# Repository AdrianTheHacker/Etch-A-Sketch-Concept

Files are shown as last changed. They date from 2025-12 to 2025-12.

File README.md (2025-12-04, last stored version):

# Etchasketch Concept
This project is designed to be a concept of what an etchasketch could be. It'll allow for modern features that aid artist ability, and truly allow them to *Draw the Future*.

## Requirements
In no particular order, the requirements are as follows:
1. Display has at least 3 colours (white counts as a colour).
2. Display can update at least once per second.
3. Users can control the drawing cursor of the display using rotary inputs which read input a minimum of every 10ms*.
4. The product should be at most 77mm by 100mm by 40mm.
5. Users can save the current drawing on the display on a laptop.
6. Different devices can share a given drawing session to collaborate on designs.

*Note that the rate in which an input is processed is independent of the rate in which the screen will be updating.

## Specifications
* [1] E-Ink display capable of displaying 3 different colours.
* [1] Single button for cycling between colours.
* [2] E-Ink screen uses effective partial updating algorithm for reducing.
* [3] Two potentiometers for reading user inputs.
* [4] PCB has width of 100mm and length of 77mm.
* [5/6] PCB contains a [pre-certified WiFi module](https://www.adafruit.com/product/4201).
* [5/6] Desktop app for managing drawing sessions and saving drawing state.

## Component Selection
Sorted by sub-system.

### Processing
[STM32G4 Hardware Configuration](https://www.st.com/resource/en/application_note/an5093-getting-started-with-stm32g4-series--hardware-development-boards-stmicroelectronics.pdf)
- [2x] [Ceramic capacitor 100nF](https://www.mouser.ca/ProductDetail/TAIYO-YUDEN/MAJCH168BB7104KTEA01?qs=ZcfC38r4PovaTBrG0IdezQ%3D%3D)
- [1x] [Ceramic capacitor 4.7uF](https://www.mouser.ca/ProductDetail/TAIYO-YUDEN/LMK107BJ475KA-T?qs=PzICbMaShUfCoRlxZeLF0g%3D%3D)
- [3x] [Ceramic capacitor 1uF (No CAD Found)](https://www.mouser.ca/ProductDetail/Murata-Electronics/GCM188M8EH105KE08D?qs=ZcfC38r4Posf7JVKT9w1zw%3D%3D)
- [1x] [Ceramic capacitor 10nF](https://www.mouser.ca/ProductDetail/KYOCERA-AVX/06035A103JAT2A?qs=Cw3yY7soYCOJ7MBOLgA8ng%3D%3D)
- [2x] [Ceramic capacitor 6.8pF (No CAD Found)](https://www.mouser.ca/ProductDetail/KYOCERA-AVX/0603YA6R8CAT2A?qs=Q0wCMCRSJ1u%252BWh5kh2d1zQ%3D%3D)
- [2x] [Ceramic capacitor 20pF](https://www.mouser.ca/ProductDetail/KYOCERA-AVX/06031A200KAT2A?qs=vKkcnSRGkVsINiHJTia7rw%3D%3D)
- [1x] [Ferrite beads (No CAD Found)](https://www.mouser.ca/ProductDetail/TE-Connectivity-Sigma-Inductors/BMC-Q1E0000H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)
- [1x] [Quartz 24MHz (No CAD Found)](https://www.mouser.ca/ProductDetail/KYOCERA-AVX/CX3225FB24000C0FZZH1?qs=Tc%252BHE9vUsnugTp3oEWKKRg%3D%3D)
- [1x] [Quartz 32.764kHz](https://www.mouser.ca/ProductDetail/Vishay-Dale/XT1312HHRXX32K76E?qs=jcD%2FCkGBYeMqyUz9UpSqCw%3D%3D)
- [1x] [Resistor 390Ω](https://www.mouser.ca/ProductDetail/Vishay-Beyschlag/MCT0603MD3900BP500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)
- [3x] [Resistor 10kΩ](https://www.mouser.ca/ProductDetail/TE-Connectivity-Holsworthy/RA73F1J10KBTDF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)
- [1x] [ST-Link Debugger (STLINK-V3MINIE)](https://www.mouser.ca/ProductDetail/STMicroelectronics/STLINK-V3MINIE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)
- [1x] [ST-Link debugger connector (LibraryLoader didn't work)](https://www.digikey.ca/en/products/detail/samtec-inc/FTSH-107-01-F-DV-K/2650001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)
- [1x] [STM32G484QET6](https://www.mouser.ca/ProductDetail/STMicroelectronics/STM32G484QET6?qs=uwxL4vQweFOef65amZQ%252BrA%3D%3D)
- [1x] [Switch (No CAD Found)](https://mou.sr/4ixqZ2V)
- [1x] [Pushbutton](https://www.mouser.ca/ProductDetail/CK/PTS125SM73SMTR21M-LFS?qs=t7xnP681wgVp4NpaUUvA%252Bw%3D%3D)

### Power
- [1x] [CR2032 Battery](https://www.mouser.ca/ProductDetail/Murata-Electronics/CR2032?qs=gTYE2QTfZfQ%2FQrgScp89FQ%3D%3D)
- [1x] [CR2032 Connector](https://www.mouser.ca/ProductDetail/Renata/SMTU2032-C?qs=UxeAxwACbqkmlMDdDbz%2FoA%3D%3D)
- [1x] [Power on LED Green](https://www.mouser.ca/ProductDetail/ams-OSRAM/KT-EELP41.12-S2U1-25-2X4X-5-R18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)
- [1x] [Resistor 100Ω (for LED) (No CAD Found, Not Requested)](https://www.mouser.ca/ProductDetail/TE-Connectivity-Holsworthy/RT73F1J100RBTD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)
- [1x] [Ceramic capacitor 10uF](https://www.mouser.ca/ProductDetail/KYOCERA-AVX/0603YD106MAT2A?qs=%252BdQmOuGyFcGTGabFXpuZrg%3D%3D)

### Display
[Screen's circuit diagram (Make manually)](https://cdn-shop.adafruit.com/product-files/6393/P6393+C22273-001_datasheet_ZJY296152-0266EABMFGN-R.pdf)
- [1x] [E-Ink display tri-colour 2.66In diagonal](https://www.adafruit.com/product/6393)
- [9x] [Ceramic capacitor 1uF](https://www.mouser.ca/ProductDetail/TAIYO-YUDEN/MAJCT168BB7105KTEA01?qs=ZcfC38r4PotKRnvquyYkSA%3D%3D)
- [1x] [Resistor 2.2Ω (No CAD Found, Not Requested)](https://www.mouser.ca/ProductDetail/Wurth-Elektronik/560112116088?qs=mELouGlnn3eIPFCFgc7e7A%3D%3D)
- [3x] [Diode](https://www.mouser.ca/ProductDetail/onsemi/MBR0530T1G?qs=3JMERSakeboS%2FFOxJUMWeg%3D%3D)
- [1x] [NMOS](https://www.mouser.ca/ProductDetail/Nexperia/NX3008NBKS115?qs=N31o%252Bt096gvSMWdFEcaa8A%3D%3D)
- [1x] [Inductor 47uH (No CAD Found, Not Requested)](https://www.mouser.ca/ProductDetail/Sumida/CDRH2D18-LDNP-470NC?qs=mT6umqgwvA1P4peHEoEcxg%3D%3D)
- [1x] [Screen connector (Downloaded, Add Manually)](https://www.digikey.ca/en/products/detail/w%C3%BCrth-elektronik/687124149022/5047796)

### Controls
- [1x] [Accelerometer](https://www.mouser.ca/ProductDetail/Analog-Devices/ADXL345BCCZ?qs=WIvQP4zGanhoa7YOkGtvEg%3D%3D)
- [1x] [Ceramic capacitor 100nF](https://www.mouser.ca/ProductDetail/TAIYO-YUDEN/MAJCH168BB7104KTEA01?qs=ZcfC38r4PovaTBrG0IdezQ%3D%3D)
- [1x] [Tantalum capacitor 1uF](https://www.mouser.ca/ProductDetail/KYOCERA-AVX/TACL105K010FTA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)
- [2x] [Potentiometer 10KΩ (Create Manually)](https://www.adafruit.com/product/3395)
- [2x] [Potentiometer cap](https://www.adafruit.com/product/2057)
- [2x] [Pushbutton](https://www.mouser.ca/ProductDetail/CK/PTS125SM73SMTR21M-LFS?qs=t7xnP681wgVp4NpaUUvA%252Bw%3D%3D)
- [2x] [Resistor 10kΩ](https://www.mouser.ca/ProductDetail/TE-Connectivity-Holsworthy/RA73F1J10KBTDF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)

### Connectivity
- [1x] [WiFi Module (Make Manually, Base off of pin headers)](https://www.adafruit.com/product/4201)
- [3x] [Pin header (Sets of 4)](https://www.mouser.ca/ProductDetail/HARTING/14120416050000?qs=sGAEpiMZZMvlX3nhDDO4ADo1TeYw%2F5hz1M8q0I2khik%3D)

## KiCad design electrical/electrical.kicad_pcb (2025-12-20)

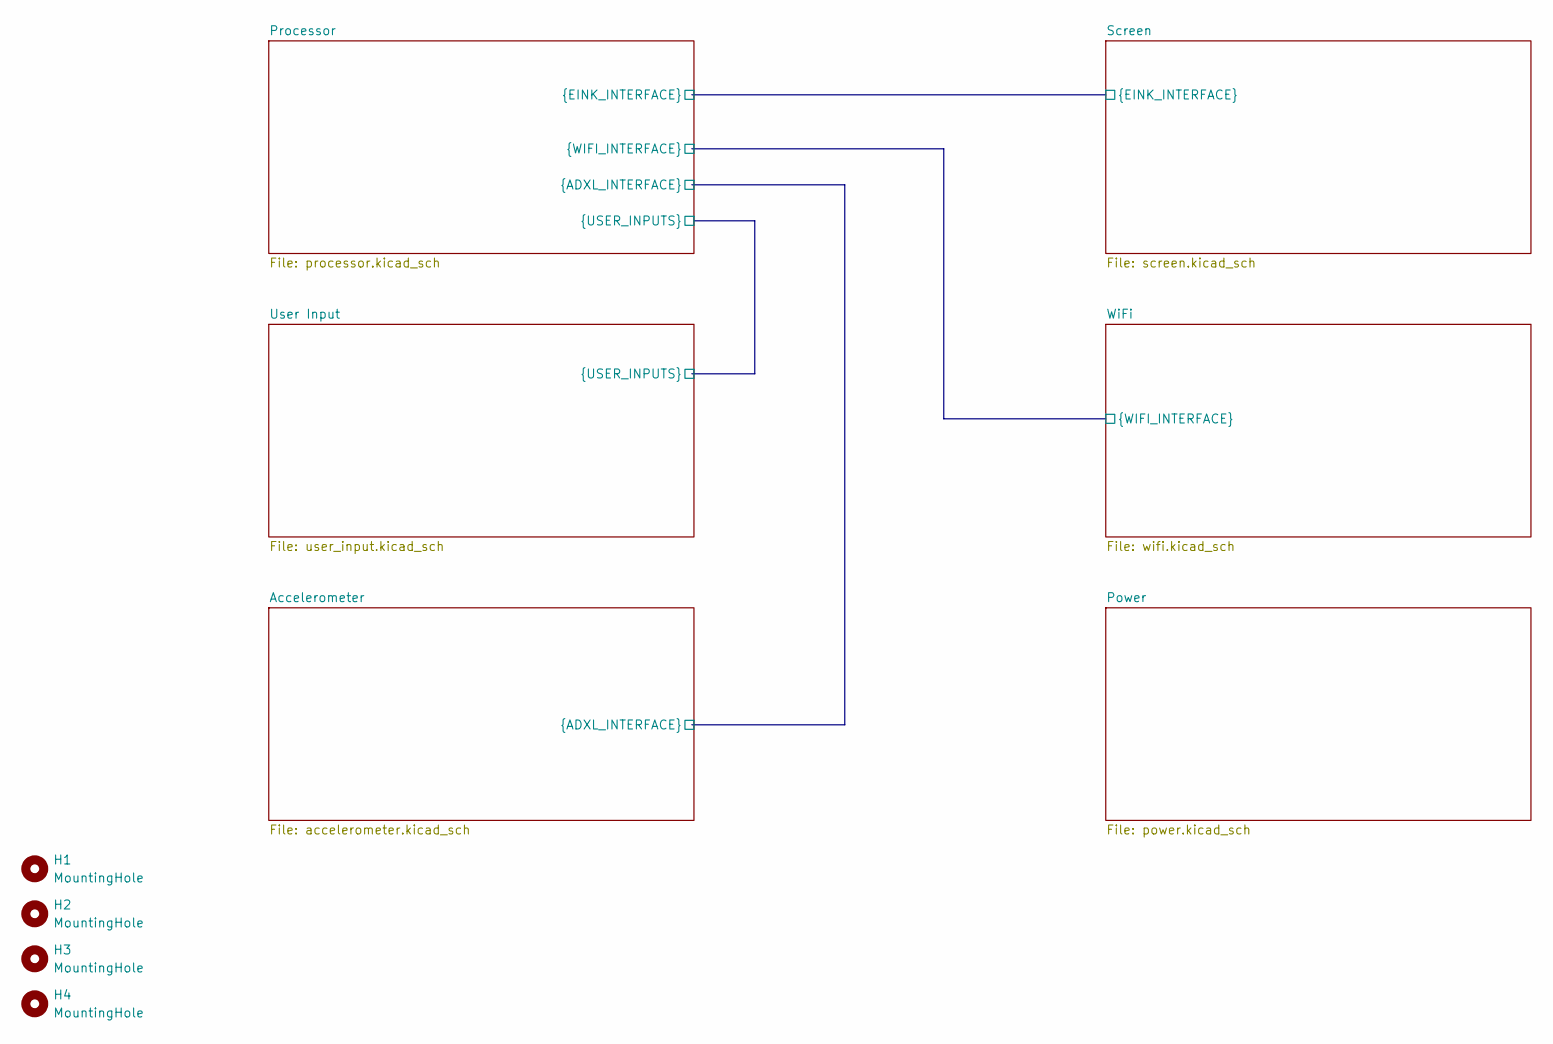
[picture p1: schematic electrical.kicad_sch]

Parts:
H1, H2, H3, H4: MountingHole; MountingHole_2.2mm_M2

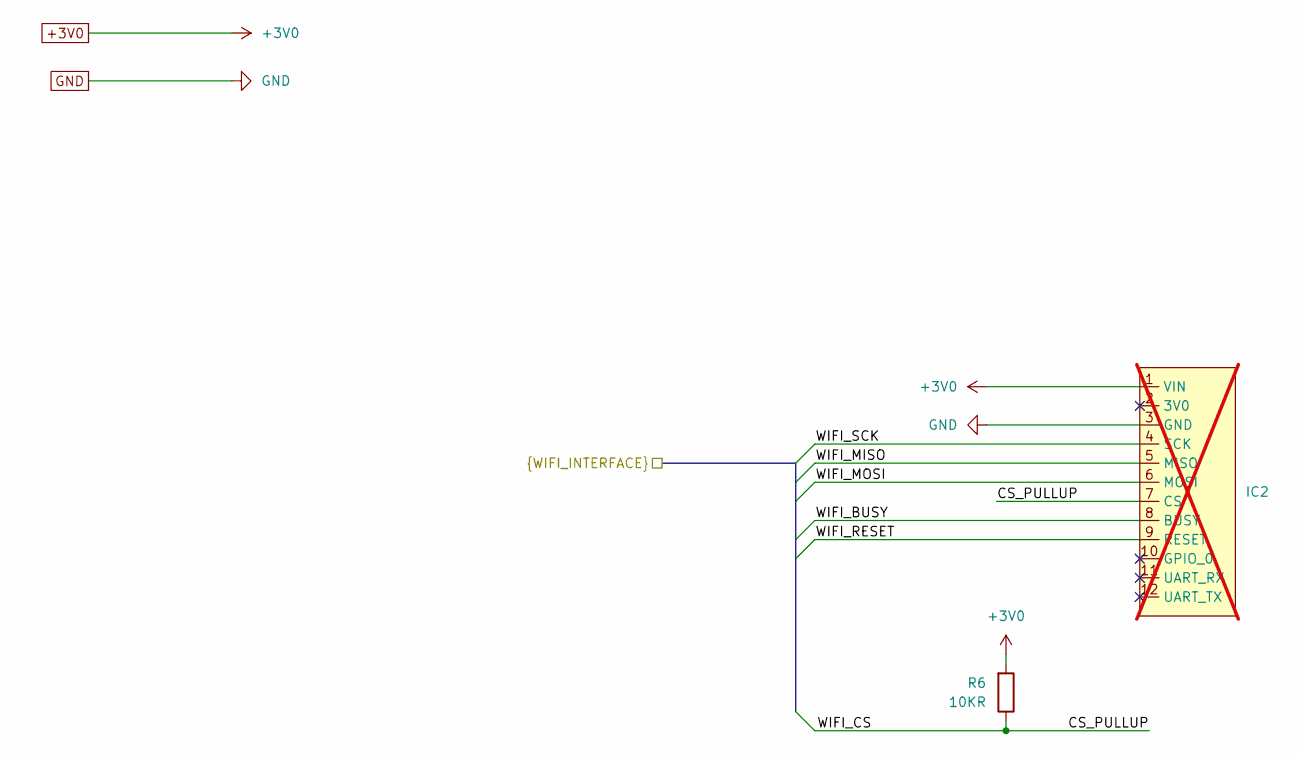
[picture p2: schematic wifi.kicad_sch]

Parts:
IC2: THT_WIFI_MODULE; not fitted
R6: 10KR; SMD_RESISTOR_0603

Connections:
+3V0: IC2.1 (VIN), R6.2; also elsewhere on the board
/Processor/WIFI_BUSY: IC2.8 (BUSY); also elsewhere on the board
/Processor/WIFI_CS: IC2.7 (CS), R6.1; also elsewhere on the board
/Processor/WIFI_MISO: IC2.5 (MISO); also elsewhere on the board
/Processor/WIFI_MOSI: IC2.6 (MOSI); also elsewhere on the board
/Processor/WIFI_RESET: IC2.9 (RESET); also elsewhere on the board
/Processor/WIFI_SCK: IC2.4 (SCK); also elsewhere on the board
GND: IC2.3 (GND); also elsewhere on the board

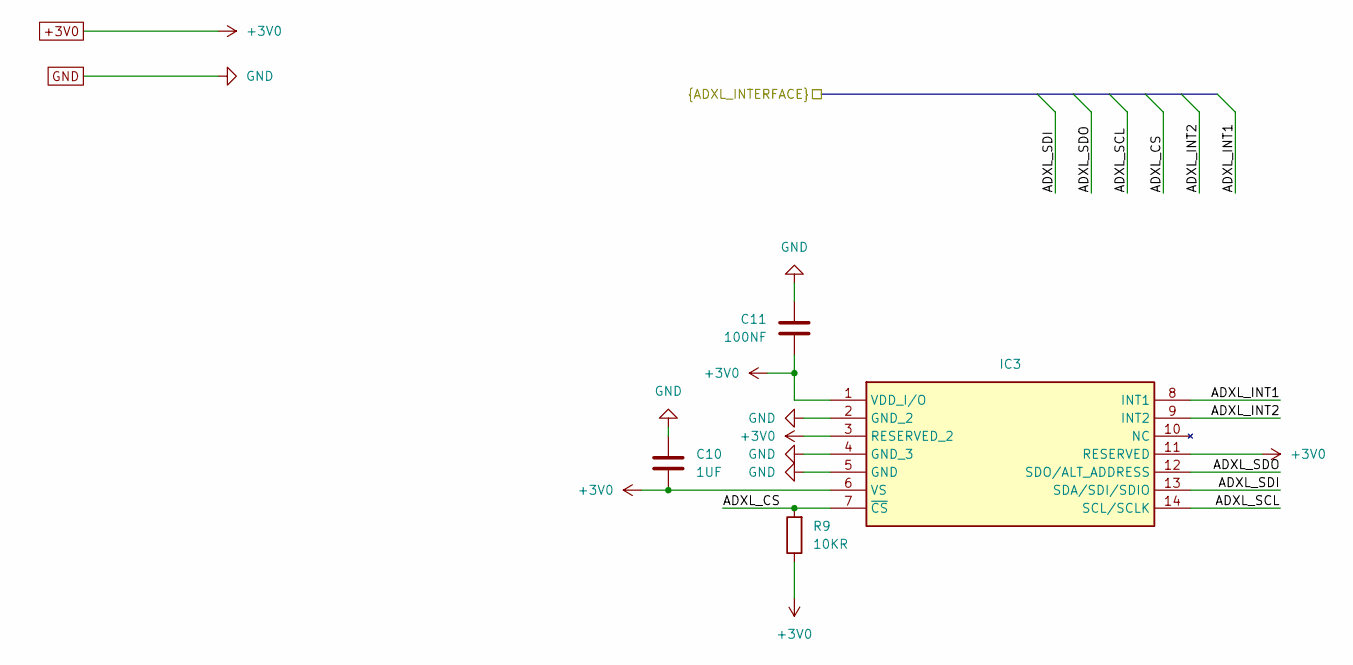
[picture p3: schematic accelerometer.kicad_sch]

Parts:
C10: 1UF; SMD_CAPACITOR_TANTALUM_0603_1UF
C11: 100NF; SMD_CAPACITOR_CERAMIC_0603
IC3: SMD_ADXL345BCCZ
R9: 10KR; SMD_RESISTOR_0603

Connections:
+3V0: C10.2, C11.1, IC3.1 (VDD_I/O), IC3.3 (RESERVED_2), IC3.6 (VS), IC3.11 (RESERVED), R9.1; also elsewhere on the board
/Accelerometer/ADXL_CS: IC3.7 (~CS), R9.2; also elsewhere on the board
/Accelerometer/ADXL_INT1: IC3.8 (INT1); also elsewhere on the board
/Accelerometer/ADXL_INT2: IC3.9 (INT2); also elsewhere on the board
/Accelerometer/ADXL_SCL: IC3.14 (SCL/SCLK); also elsewhere on the board
/Accelerometer/ADXL_SDI: IC3.13 (SDA/SDI/SDIO); also elsewhere on the board
/Accelerometer/ADXL_SDO: IC3.12 (SDO/ALT_ADDRESS); also elsewhere on the board
GND: C10.1, C11.2, IC3.2 (GND_2), IC3.4 (GND_3), IC3.5 (GND); also elsewhere on the board

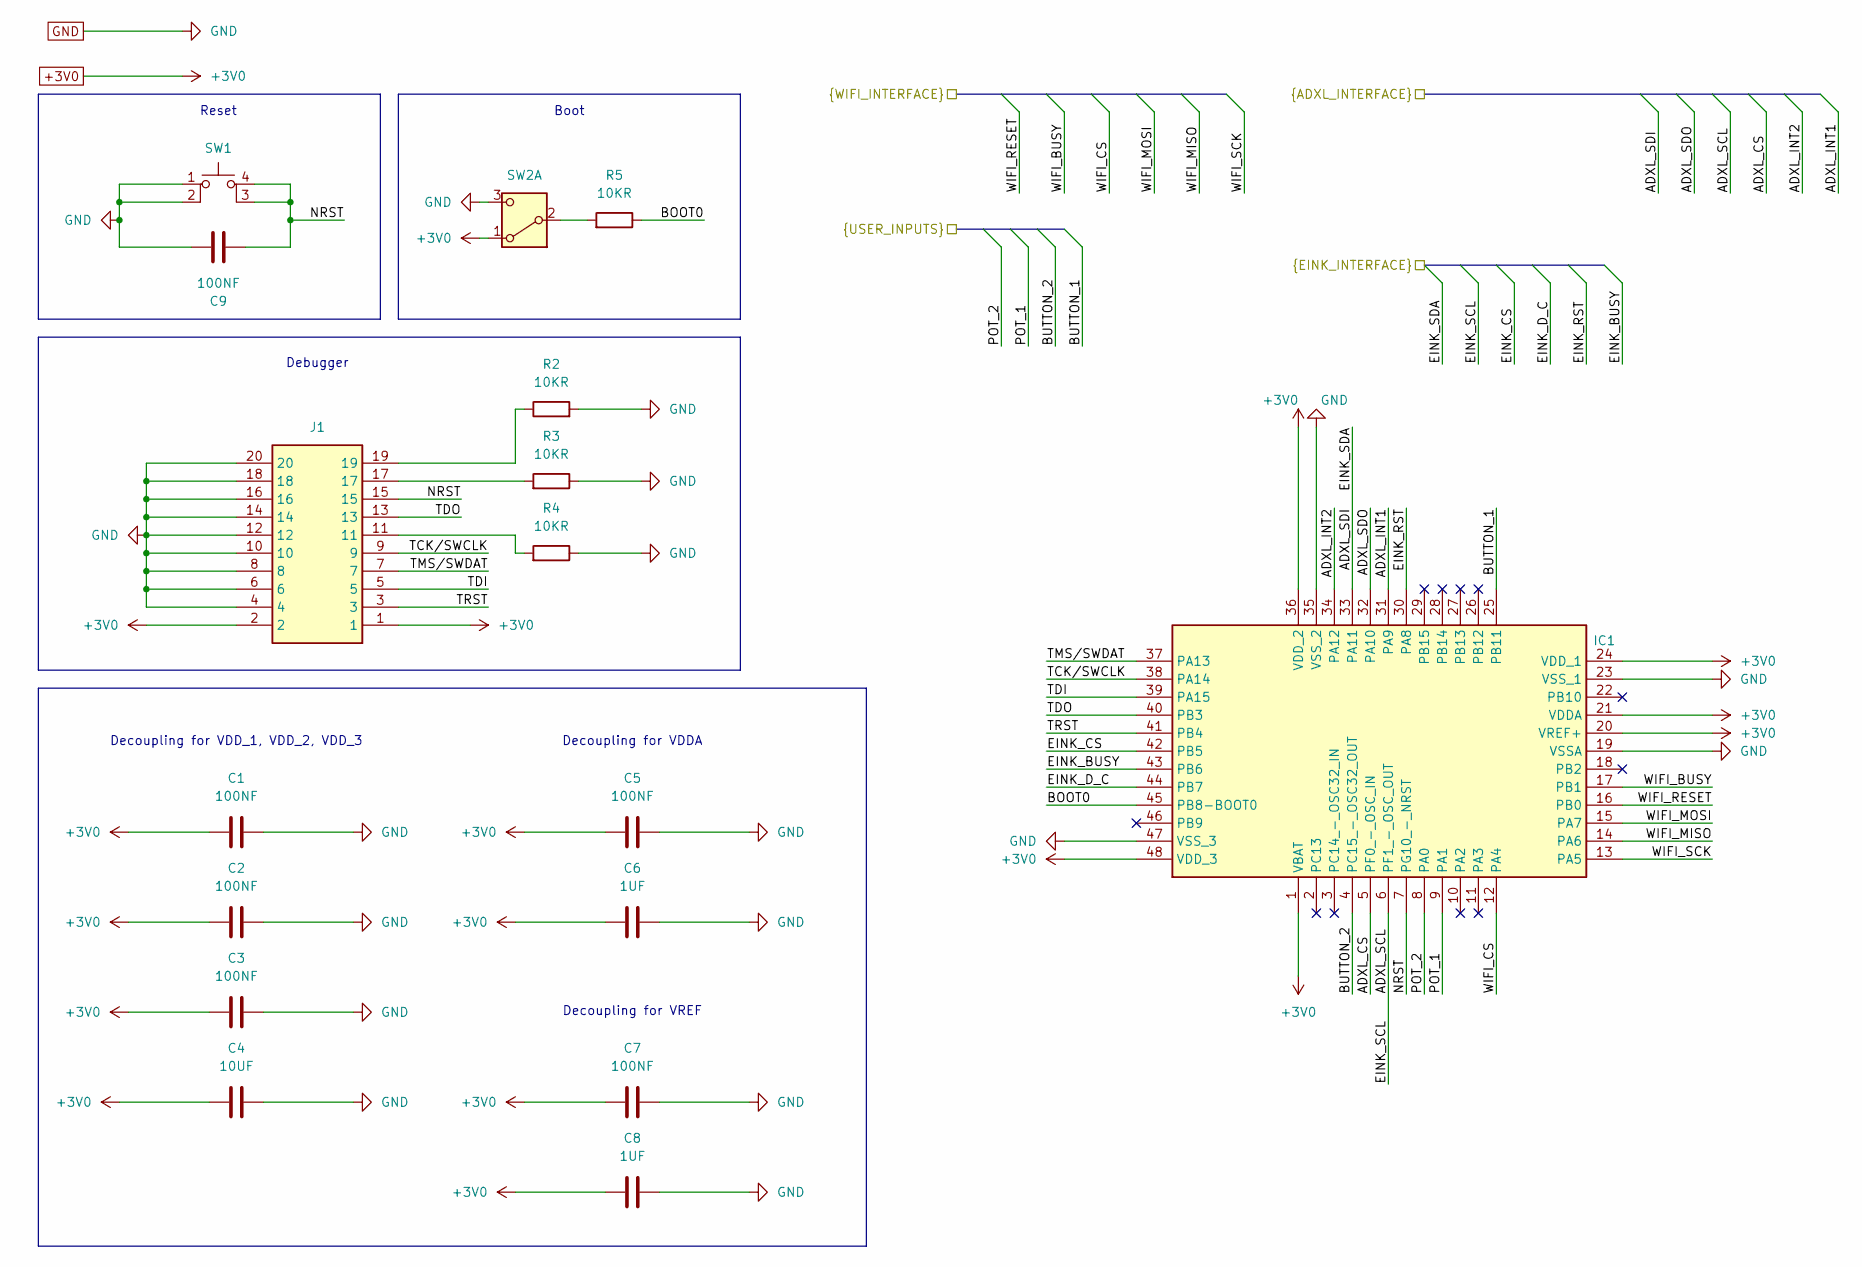
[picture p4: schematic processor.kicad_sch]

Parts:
C1, C2, C3, C5, C7, C9: 100NF; SMD_CAPACITOR_CERAMIC_0603
C4: 10UF; SMD_CAPACITOR_CERAMIC_0603
C6, C8: 1UF; SMD_CAPACITOR_CERAMIC_0603
IC1: STM32G474CBT6TR; SMD_STM32G474CBT6TR
J1: 24 Pins; THT_CONNECTOR_JTAG_SWD
R2, R3, R4, R5: 10KR; SMD_RESISTOR_0603
SW1: SMD_BUTTON
SW2: SMD_SWITCH_HORIZONTAL

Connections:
+3V0: C1.2, C2.2, C3.2, C4.1, C5.2, C6.1, C7.2, C8.1, IC1.1 (VBAT), IC1.20 (VREF+), IC1.21 (VDDA), IC1.24 (VDD_1), IC1.36 (VDD_2), IC1.48 (VDD_3), J1.1, J1.2, SW2.1 (A); also elsewhere on the board
/Accelerometer/ADXL_CS: IC1.5 (PF0_-_OSC_IN); also elsewhere on the board
/Accelerometer/ADXL_INT1: IC1.31 (PA9); also elsewhere on the board
/Accelerometer/ADXL_INT2: IC1.34 (PA12); also elsewhere on the board
/Accelerometer/ADXL_SCL: IC1.6 (PF1_-_OSC_OUT); also elsewhere on the board
/Accelerometer/ADXL_SDI: IC1.33 (PA11); also elsewhere on the board
/Accelerometer/ADXL_SDO: IC1.32 (PA10); also elsewhere on the board
/Processor/BOOT0: IC1.45 (PB8-BOOT0), R5.1
/Processor/BUTTON_1: IC1.25 (PB11); also elsewhere on the board
/Processor/BUTTON_2: IC1.4 (PC15_-_OSC32_OUT); also elsewhere on the board
/Processor/EINK_BUSY: IC1.43 (PB6); also elsewhere on the board
/Processor/EINK_CS: IC1.42 (PB5); also elsewhere on the board
/Processor/EINK_D_C: IC1.44 (PB7); also elsewhere on the board
/Processor/EINK_RST: IC1.30 (PA8); also elsewhere on the board
/Processor/NRST: C9.1, IC1.7 (PG10_-_NRST), J1.15, SW1.3 (K), SW1.4 (A)
/Processor/POT_1: IC1.9 (PA1); also elsewhere on the board
/Processor/POT_2: IC1.8 (PA0); also elsewhere on the board
/Processor/TCK/SWCLK: IC1.38 (PA14), J1.9
/Processor/TDI: IC1.39 (PA15), J1.5
/Processor/TDO: IC1.40 (PB3), J1.13
/Processor/TMS/SWDAT: IC1.37 (PA13), J1.7
/Processor/TRST: IC1.41 (PB4), J1.3
/Processor/WIFI_BUSY: IC1.17 (PB1); also elsewhere on the board
/Processor/WIFI_CS: IC1.12 (PA4); also elsewhere on the board
/Processor/WIFI_MISO: IC1.14 (PA6); also elsewhere on the board
/Processor/WIFI_MOSI: IC1.15 (PA7); also elsewhere on the board
/Processor/WIFI_RESET: IC1.16 (PB0); also elsewhere on the board
/Processor/WIFI_SCK: IC1.13 (PA5); also elsewhere on the board
GND: C1.1, C2.1, C3.1, C4.2, C5.1, C6.2, C7.1, C8.2, C9.2, IC1.19 (VSSA), IC1.23 (VSS_1), IC1.35 (VSS_2), IC1.47 (VSS_3), J1.4, J1.6, J1.8, J1.10, J1.12, J1.14, J1.16, J1.18, J1.20, R2.2, R3.1, R4.1, SW1.1, SW1.2, SW2.3 (C); also elsewhere on the board
unnamed: J1.11, R4.2
unnamed: J1.17, R3.2
unnamed: J1.19, R2.1
unnamed: R5.2, SW2.2 (B)

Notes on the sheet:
Debugger
Reset
Boot
Decoupling for VDDA
Decoupling for VDD_1, VDD_2, VDD_3
Decoupling for VREF

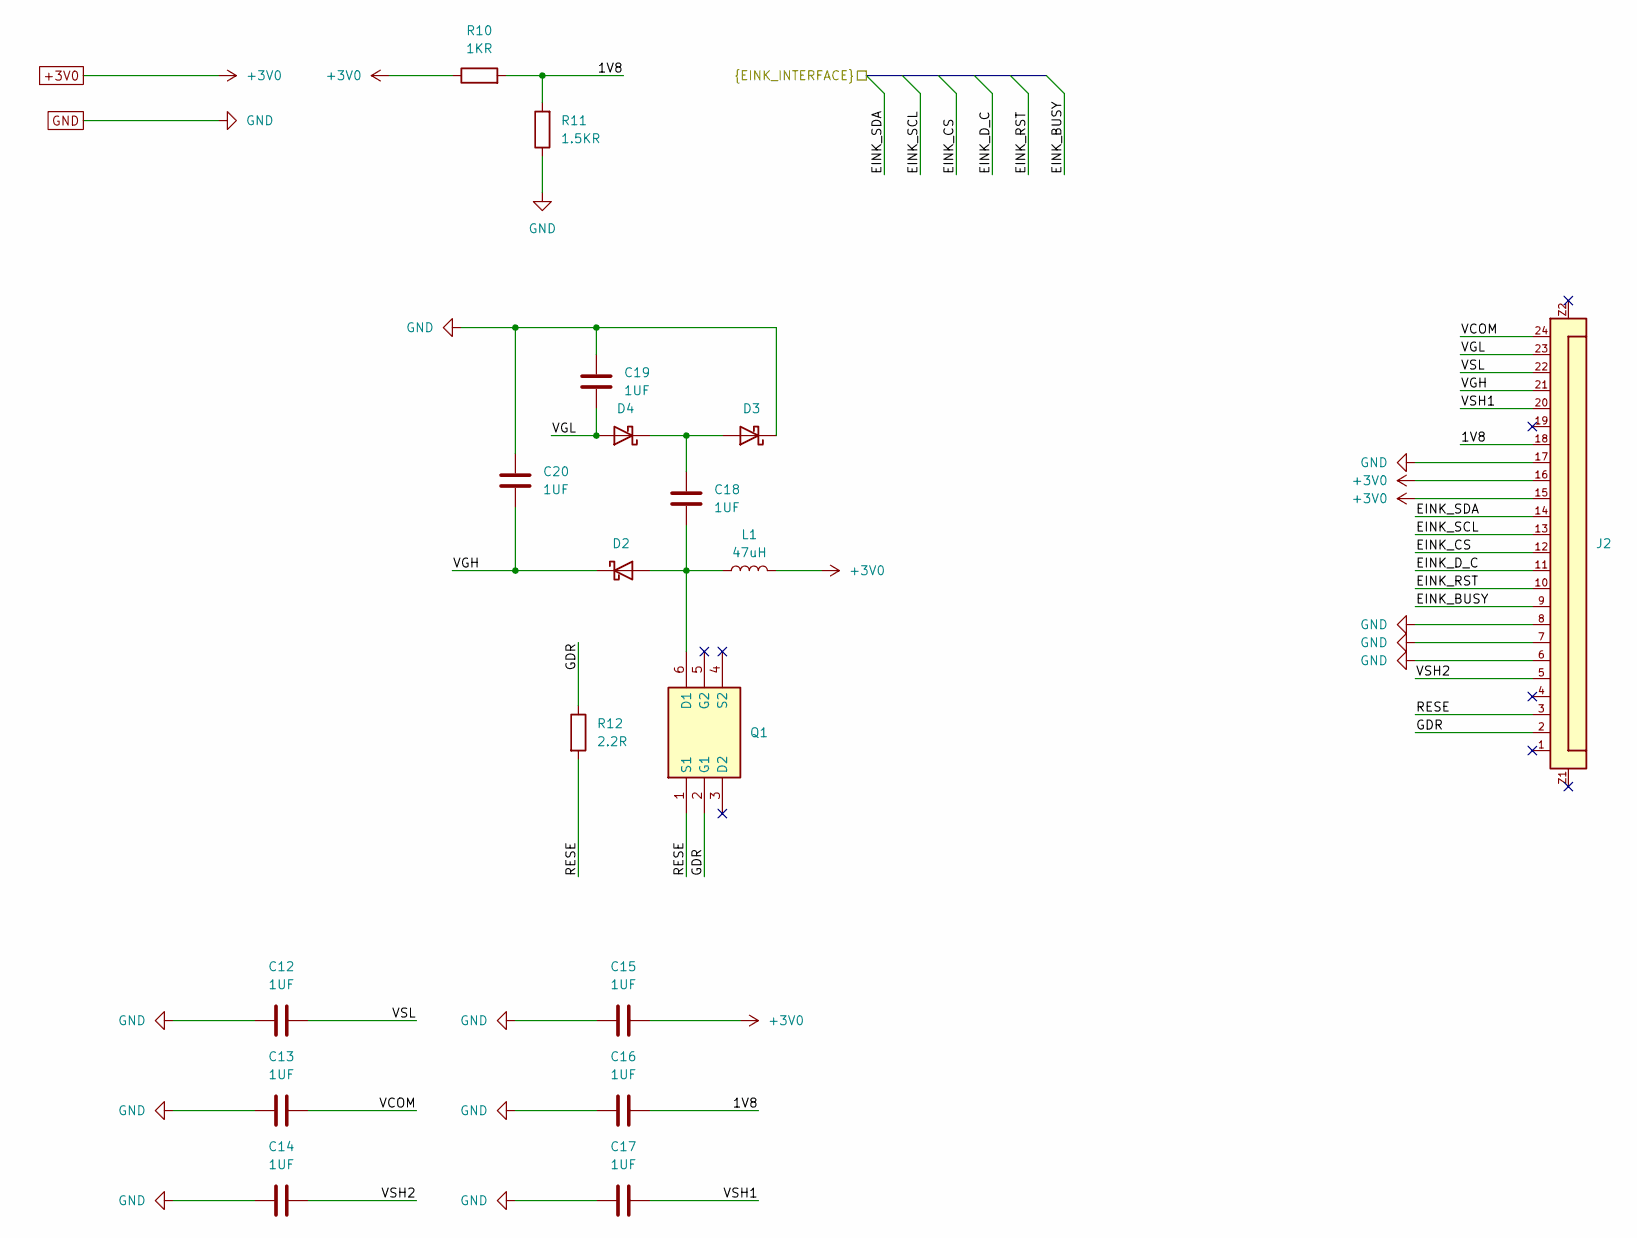
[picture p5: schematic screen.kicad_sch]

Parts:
C12, C13, C14, C15, C16, C17, C18, C19, C20: 1UF; SMD_CAPACITOR_CERAMIC_0603
D2, D3, D4: SMD_DIODE_MBR0530T1G
J2: 6871XX149022_687124149022; SMD_CONNECTOR_RIBBON_CABLE_24_PINS
L1: 47uH; SMD_INDUCTOR_0603
Q1: SMD_MOSFET_NX3008NBKS
R10: 1KR; SMD_RESISTOR_0603
R11: 1.5KR; SMD_RESISTOR_0603
R12: 2.2R; SMD_RESISTOR_0603

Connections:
+3V0: C15.2, J2.15, J2.16, L1.2, R10.1; also elsewhere on the board
/Accelerometer/ADXL_SCL: J2.13; also elsewhere on the board
/Accelerometer/ADXL_SDI: J2.14; also elsewhere on the board
/Processor/EINK_BUSY: J2.9; also elsewhere on the board
/Processor/EINK_CS: J2.12; also elsewhere on the board
/Processor/EINK_D_C: J2.11; also elsewhere on the board
/Processor/EINK_RST: J2.10; also elsewhere on the board
/Screen/1V8: C16.2, J2.18, R10.2, R11.2
/Screen/GDR: J2.2, Q1.2 (G1), R12.2
/Screen/RESE: J2.3, Q1.1 (S1), R12.1
/Screen/VCOM: C13.1, J2.24
/Screen/VGH: C20.2, D2.1 (K), J2.21
/Screen/VGL: C19.1, D4.2 (A), J2.23
/Screen/VSH1: C17.2, J2.20
/Screen/VSH2: C14.2, J2.5
/Screen/VSL: C12.1, J2.22
GND: C12.2, C13.2, C14.1, C15.1, C16.1, C17.1, C19.2, C20.1, D3.1 (K), J2.6, J2.7, J2.8, J2.17, R11.1; also elsewhere on the board
unnamed: C18.1, D2.2 (A), L1.1, Q1.6 (D1)
unnamed: C18.2, D3.2 (A), D4.1 (K)

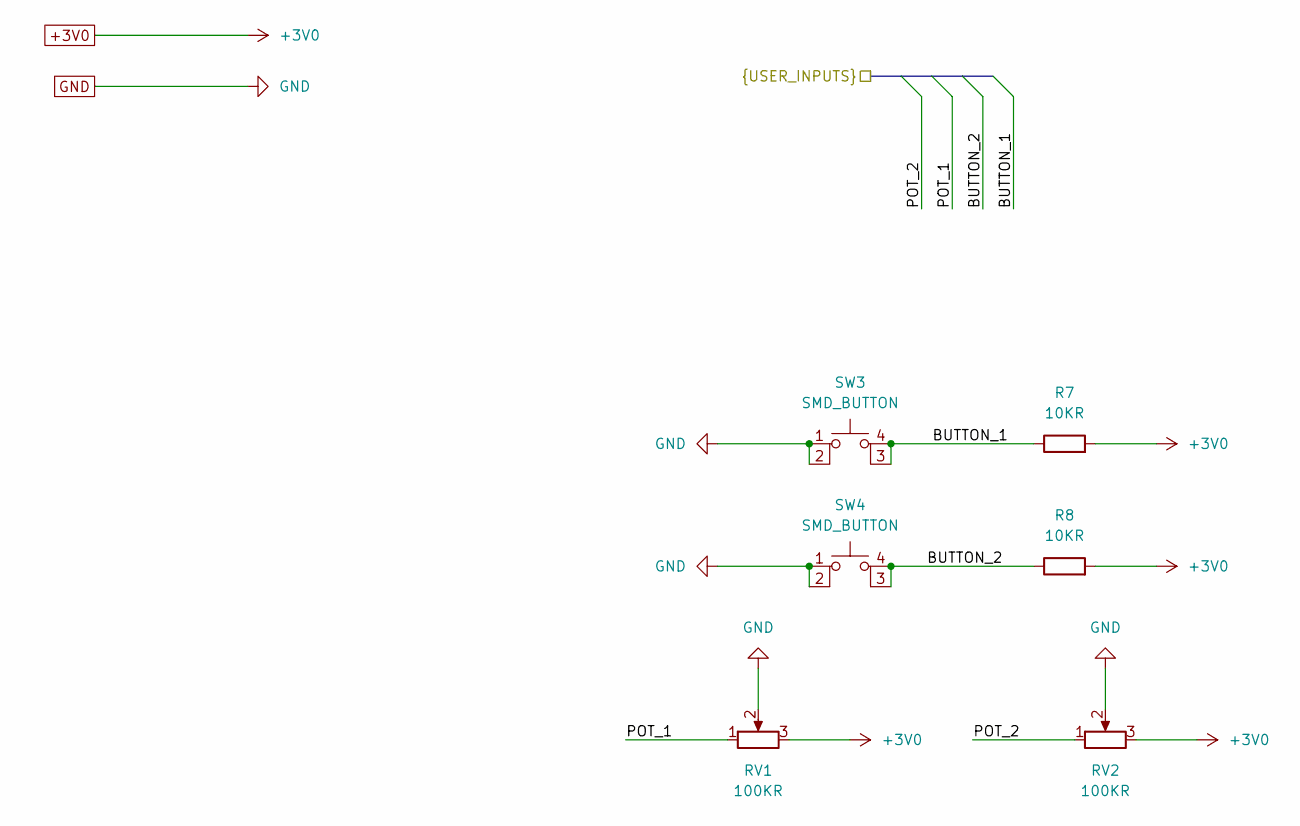
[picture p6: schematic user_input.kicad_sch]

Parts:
R7, R8: 10KR; SMD_RESISTOR_0603
RV1, RV2: 100KR; THT_POTENTIOMETER_100KR
SW3, SW4: SMD_BUTTON

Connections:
+3V0: R7.2, R8.2, RV1.3, RV2.3; also elsewhere on the board
/Processor/BUTTON_1: R7.1, SW3.3 (K), SW3.4 (A); also elsewhere on the board
/Processor/BUTTON_2: R8.1, SW4.3 (K), SW4.4 (A); also elsewhere on the board
/Processor/POT_1: RV1.1; also elsewhere on the board
/Processor/POT_2: RV2.1; also elsewhere on the board
GND: RV1.2, RV2.2, SW3.1, SW3.2, SW4.1, SW4.2; also elsewhere on the board

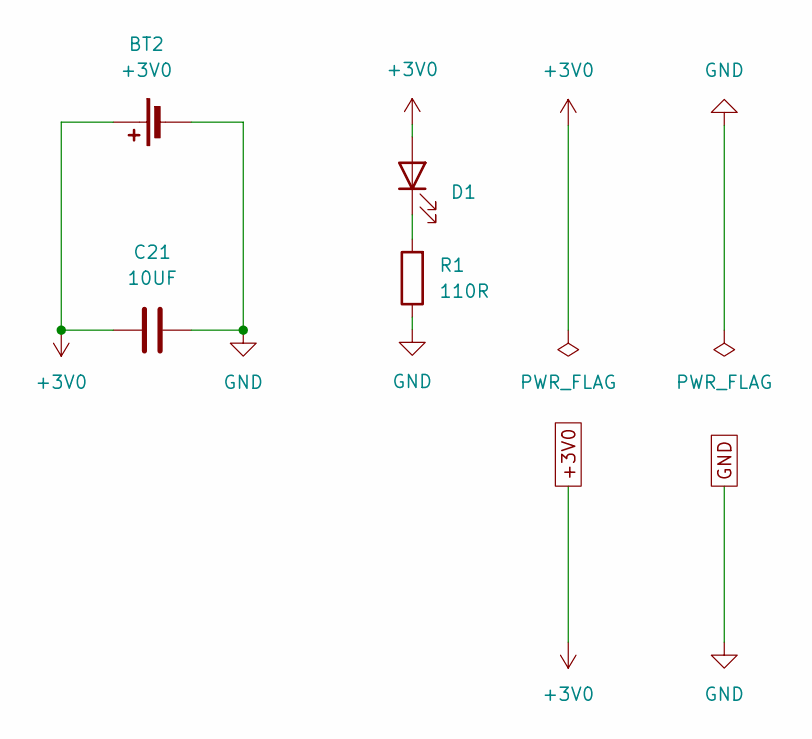
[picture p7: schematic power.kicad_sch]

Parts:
BT2: +3V0; SMD_BATTERY_SINGLE_CELL_CR2032
C21: 10UF; SMD_CAPACITOR_CERAMIC_0603
D1: Green; SMD_LED_GREEN_0603
R1: 110R; SMD_RESISTOR_0603

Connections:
+3V0: BT2.1 (+), C21.1, D1.2 (A); also elsewhere on the board
GND: BT2.2 (-), C21.2, R1.1; also elsewhere on the board
unnamed: D1.1 (K), R1.2

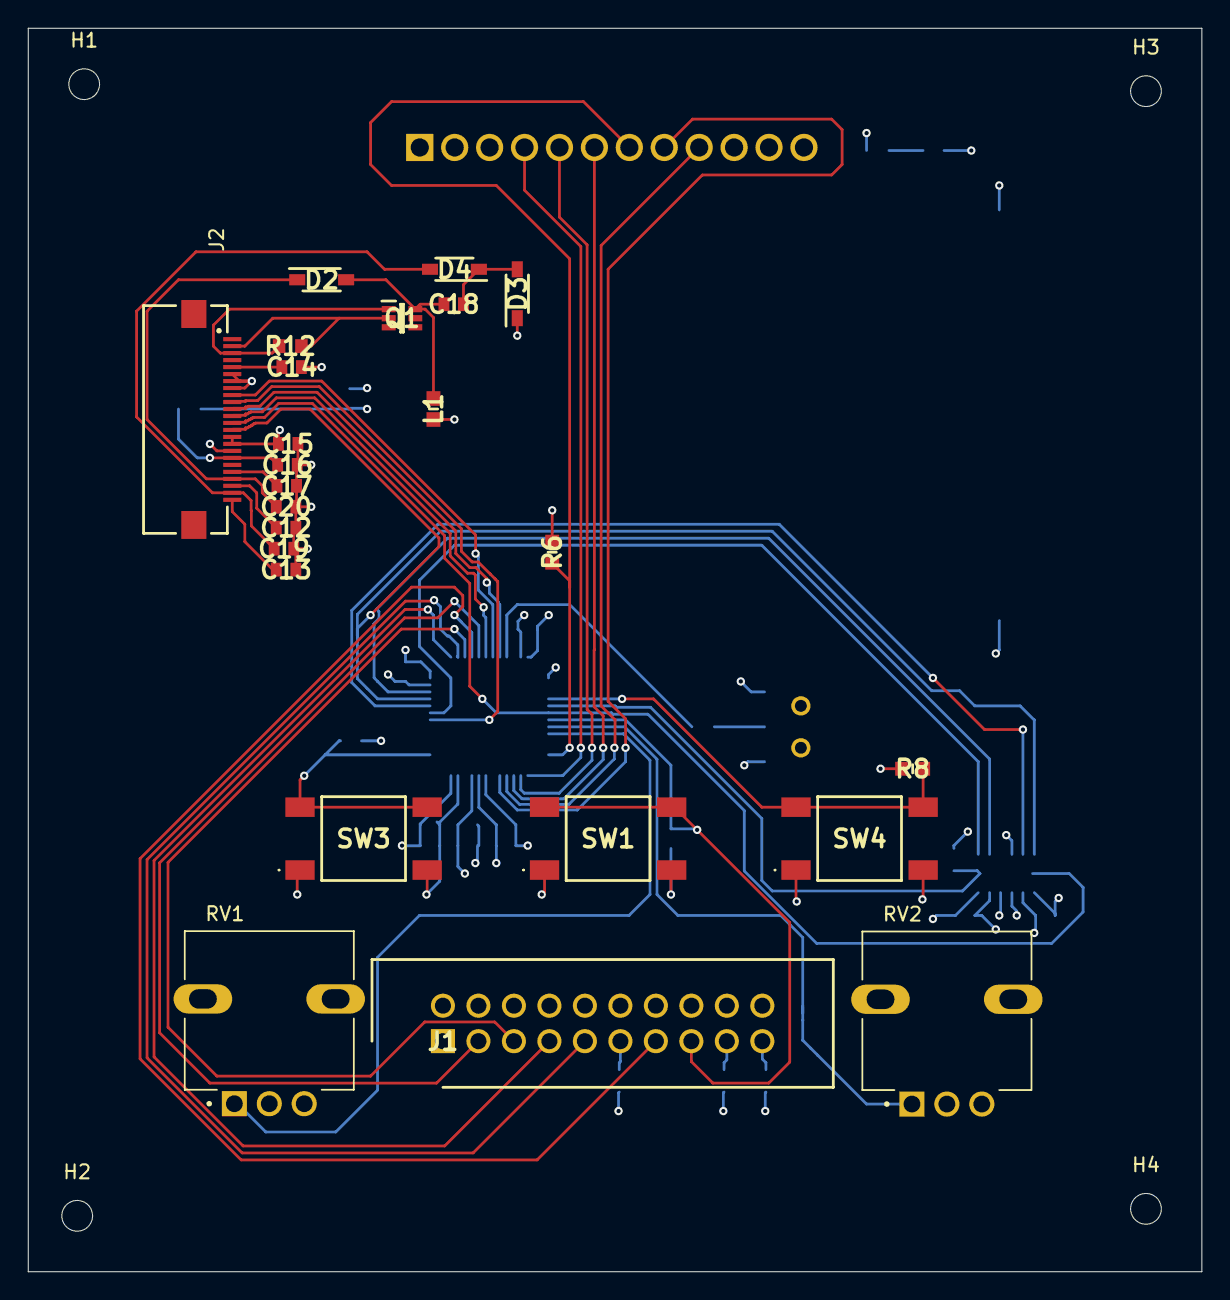
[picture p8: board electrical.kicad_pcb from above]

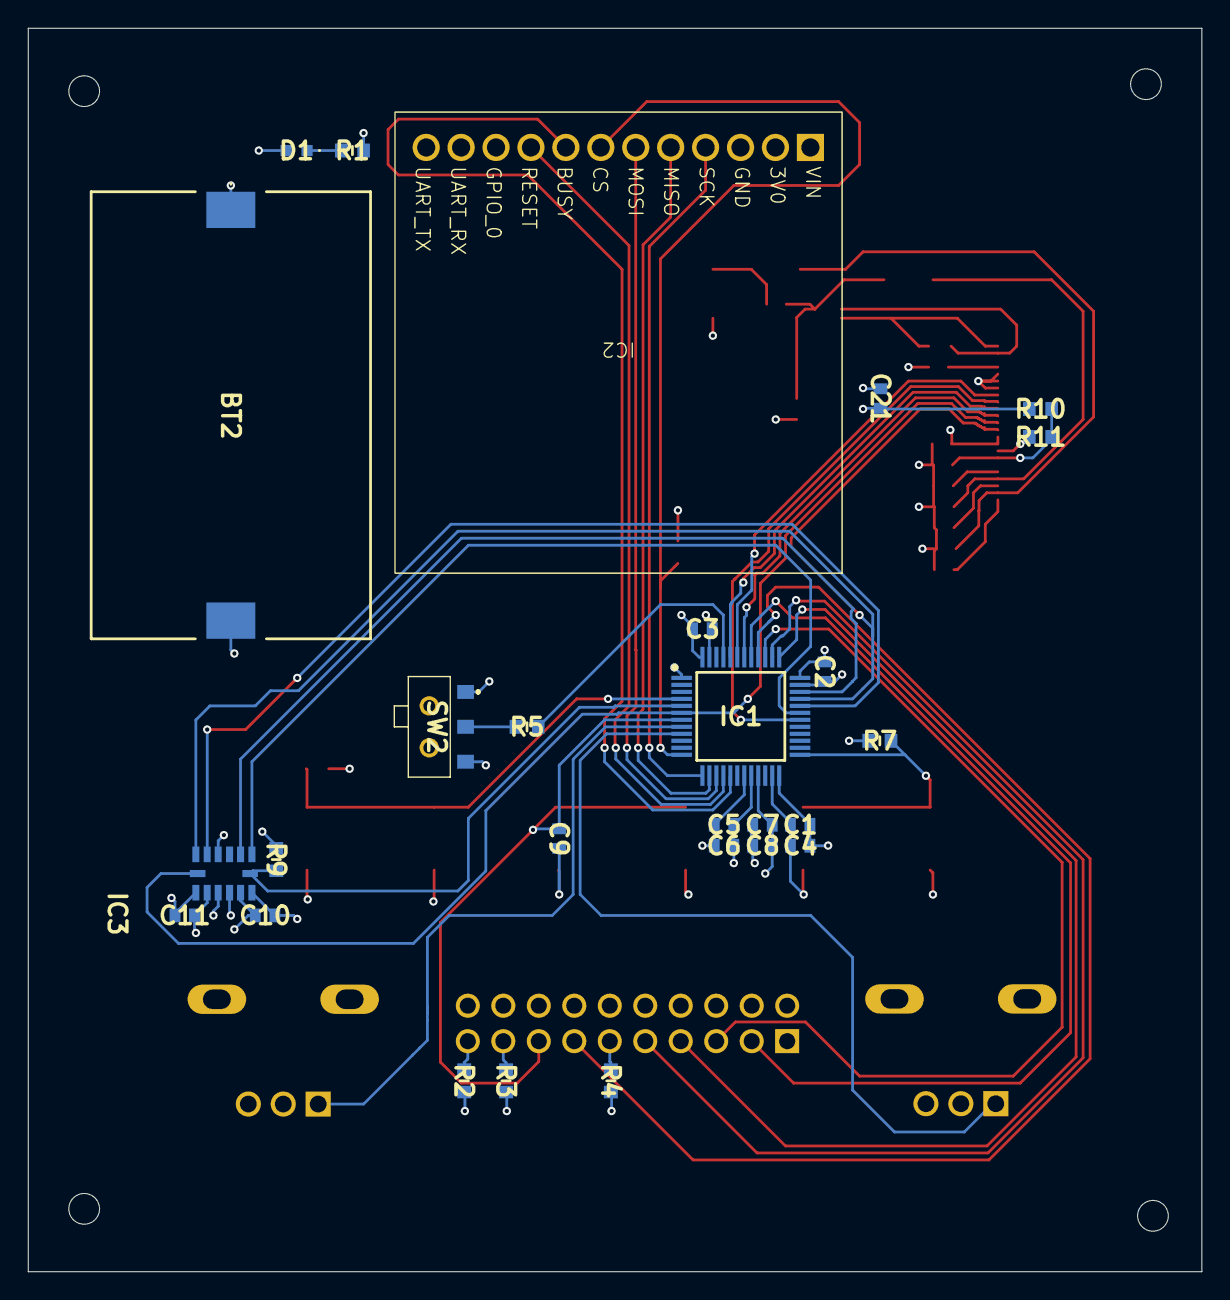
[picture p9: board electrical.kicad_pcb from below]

Board: 4 copper layers, 84.0 x 89.0 mm, 55 parts (27 on the bottom side), 45 nets.

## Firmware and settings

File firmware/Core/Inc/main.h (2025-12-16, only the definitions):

#define BUTTON_2_Pin GPIO_PIN_15
#define BUTTON_2_GPIO_Port GPIOC
#define ADXL_CS_Pin GPIO_PIN_0
#define ADXL_CS_GPIO_Port GPIOF
#define ADXL_EINK_SCK_Pin GPIO_PIN_1
#define ADXL_EINK_SCK_GPIO_Port GPIOF
#define POT_2_Pin GPIO_PIN_0
#define POT_2_GPIO_Port GPIOA
#define POT_1_Pin GPIO_PIN_1
#define POT_1_GPIO_Port GPIOA
#define BUTTON_1_Pin GPIO_PIN_2
#define BUTTON_1_GPIO_Port GPIOA
#define WIFI_CS_Pin GPIO_PIN_4
#define WIFI_CS_GPIO_Port GPIOA
#define WIFI_SCK_Pin GPIO_PIN_5
#define WIFI_SCK_GPIO_Port GPIOA
#define WIFI_MISO_Pin GPIO_PIN_6
#define WIFI_MISO_GPIO_Port GPIOA
#define WIFI_MOSI_Pin GPIO_PIN_7
#define WIFI_MOSI_GPIO_Port GPIOA
#define WIFI_RESET_Pin GPIO_PIN_0
#define WIFI_RESET_GPIO_Port GPIOB
#define WIFI_BUSY_Pin GPIO_PIN_1
#define WIFI_BUSY_GPIO_Port GPIOB
#define EINK_RST_Pin GPIO_PIN_8
#define EINK_RST_GPIO_Port GPIOA
#define ADXL_INT1_Pin GPIO_PIN_9
#define ADXL_INT1_GPIO_Port GPIOA
#define ADXL_EINK_MISO_Pin GPIO_PIN_10
#define ADXL_EINK_MISO_GPIO_Port GPIOA
#define ADXL_EINK_MOSI_Pin GPIO_PIN_11
#define ADXL_EINK_MOSI_GPIO_Port GPIOA
#define ADXL_INT2_Pin GPIO_PIN_12
#define ADXL_INT2_GPIO_Port GPIOA
#define EINK_CS_Pin GPIO_PIN_5
#define EINK_CS_GPIO_Port GPIOB
#define EINK_BUSY_Pin GPIO_PIN_6
#define EINK_BUSY_GPIO_Port GPIOB
#define EINK_D_C_Pin GPIO_PIN_7
#define EINK_D_C_GPIO_Port GPIOB

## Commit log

2025-10-07 Adding electrical stuff
    [etchasketch_design_concept.kicad_pcb, etchasketch_design_concept.kicad_sch]
2025-10-08 #3 Creating symbol library and symbol for E-Ink display.
    [Circuit_Design_V1.kicad_pcb, Circuit_Design_V1.kicad_sch]
2025-10-08 #3 Implementing symbol for coincell battery case and updating symbol datasheets and descriptions.
2025-10-08 #3 Improving the coincell battery holder symbol.
    [Circuit_Design_V1.kicad_sch]
2025-10-08 #3 Connecting MCU connectors to E-Ink on schematic.
    [Circuit_Design_V1.kicad_sch]
2025-10-08 #3 Creating symbol for accelerometer.
2025-10-11 #3 Creating the system diagram.
    [Accelerometer.kicad_sch, Bluetooth.kicad_sch, Circuit_Design_V1.kicad_sch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]
2025-10-11 #3 Creating power sub-schematic.
    [Accelerometer.kicad_sch, Bluetooth.kicad_sch, Display.kicad_sch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]
2025-10-11 #3 Sourcing capacitors, and designing power for MCU.
    [Accelerometer.kicad_sch, Bluetooth.kicad_sch, Display.kicad_sch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]
2025-10-11 #3 Adding accelerometer to schematic.
    [Accelerometer.kicad_sch, Bluetooth.kicad_sch, Display.kicad_sch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]
2025-10-17 #3 Improving accelerometer schematic.
    [Accelerometer.kicad_sch, Bluetooth.kicad_sch, Display.kicad_sch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]
2025-10-17 #3 Adding footprints for capacitors.
    [MCU.kicad_sch]
2025-10-17 #3 Making symbols.
    [Display.kicad_sch, MCU.kicad_sch, Powerkicad_sch.kicad_sch]
2025-10-17 #3 Finishing some circuitry.
    [Accelerometer.kicad_sch, Display.kicad_sch, MCU.kicad_sch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]
2025-10-21 Making minor fixes to the schematic.
    [Display.kicad_sch]
2025-10-22 Finishing schematic
    [MCU.kicad_sch]
2025-10-22 Completing schematic.
    [Accelerometer.kicad_sch, Bluetooth.kicad_sch, Display.kicad_sch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]
2025-10-22 Generating BOM.
2025-10-22 Adding pots.
    [MCU.kicad_sch]
2025-11-07 #10 Updating the project's requirements.
    [Accelerometer.kicad_sch, Bluetooth.kicad_sch, Circuit_Design_V1.kicad_pcb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]
2025-11-22 #14 Adding STM32's docs on hardware configuration.
2025-11-22 #14 Completing component selection for power
2025-11-22 #19 Implementing top level sheets.
    [connectivity.kicad_sch, controls.kicad_sch, display.kicad_sch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]
2025-11-22 #18 Adding decoupling capacitor.
    [connectivity.kicad_sch, controls.kicad_sch, display.kicad_sch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]
2025-11-22 #3 Completing power section.
    [electrical.kicad_sch]
2025-11-22 #3 Making minor changes to power.
    [power.kicad_sch]
2025-11-23 #3 Implementing base schematic for processor.
    [electrical.kicad_sch, power.kicad_sch, processor.kicad_sch]
2025-11-30 #3 Implementing potentionometers and beginning IOC file creation.
    [controls.kicad_sch, electrical.kicad_sch, processor.kicad_sch]
2025-11-30 #3 Adding controls connections to STM32, updating IOC file to match.
    [connectivity.kicad_sch, controls.kicad_sch, display.kicad_sch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]
2025-11-30 #3 Adding WiFi module to the schematic.
    [connectivity.kicad_sch, display.kicad_sch, processor.kicad_sch]
2025-12-01 #3 Updating schematic.
    [connectivity.kicad_sch, controls.kicad_sch, display.kicad_sch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]
2025-12-04 #3 Finding CAD for switch.
    [display.kicad_sch, processor.kicad_sch]
2025-12-04 not in working state yet.
    [controls.kicad_sch, electrical.kicad_pcb, electrical.kicad_sch]
2025-12-06 #17 Making layout. Errors rpesent.
    [AAA.kicad_sch, connectivity.kicad_sch, controls.kicad_sch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]
2025-12-06 #17 Finish PCB layout.
    [3395.stp, electrical.kicad_pcb]
2025-12-09 Adding gerbers.
    [electrical-B_Cu.gbr, electrical-B_Mask.gbr, electrical-B_Paste.gbr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]
2025-12-16 Making progress on schematic and developing IOC.
    [accelerometer.kicad_sch, electrical.kicad_pcb, electrical.kicad_sch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]
2025-12-16 Adding gitignore
    [3395.stp, AAA.kicad_sch, connectivity.kicad_sch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]
2025-12-16 Adding user input.
    [electrical.kicad_sch, power.kicad_sch, processor.kicad_sch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]
2025-12-16 Adding decoupling capacitors for STM.
    [electrical.kicad_pcb, electrical.kicad_sch, power.kicad_sch]
2025-12-16 Adding more to layout.
    [electrical.kicad_pcb, processor.kicad_sch]
2025-12-17 Completing PCB layout.
    [electrical.csv, electrical.kicad_pcb, electrical.kicad_sch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]
2025-12-17 Adding stuff
    [electrical.kicad_pcb]
2025-12-18 Adding build files.
    [electrical-B_Cu.gbr, electrical-B_Mask.gbr, electrical-B_Paste.gbr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]
2025-12-20 Improving manufacturability of the board.
    [electrical-B_Cu.gbr, electrical-B_Mask.gbr, electrical-B_Paste.gbr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]
2026-01-05 Adding manufacturer and manufacturer number to path.
    [accelerometer.kicad_sch, electrical.csv, electrical.kicad_sch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]
2026-01-10 Updating schematic pages.
    [accelerometer.kicad_sch, electrical.kicad_sch, power.kicad_sch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]

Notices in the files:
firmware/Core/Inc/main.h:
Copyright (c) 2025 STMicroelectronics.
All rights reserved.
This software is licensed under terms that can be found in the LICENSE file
